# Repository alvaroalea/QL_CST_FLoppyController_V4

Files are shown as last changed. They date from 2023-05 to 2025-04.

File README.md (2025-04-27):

# QL_CST_FLoppyController

A clone of some version of the CST's Floppy Disk Interface for Sinclair QL

## History

CST was one of the main manufacturer of add-on for the Sinclair QL computer, this include backplanes, memory expansions and disc interfaces.

The Disk interface evolved over several version, with enhaced compatibilities in each version.

- Issue 1 - I can't get information about this Issue on internet.
- Issue 2 - This version use ReVision 1.13 (C) 1985 of the ROM, of 8Kb, Nicolaos Doukas draw the schematic an create a clone. Is possible to upgrade Issue 2 to ROM 1.16 if isolate the PIN 3 of IC3 (74LS03).
- Issue 3 - This version use Revision 1.16 (C) 198X of the ROM, of 8Kb, new clock circuit and 1 missing track on the PCB (and this is the reason you need to isolate pin 3 on Issue 2)
- Issue 4 - This version use Revision 1.18 (C) 1986 /1.19 (C) 1987 of the ROM, diferent circuit, increase the ROM size to 12Kb (use a 16Kb Eprom chip), now include RAM disk driver in rom, this version se a scrambled ROM, so when read with a external device, you can see the code.

Version 1.19 of ROM is missing in action, other version area available to download here: https://dilwyn.theqlforum.com/qlrom/index.html

Has been seen version of Issue 4 with, the top/botton cooper tracks interchanged, this help to reverse engineered the complete board.

Nowday I have draw and test the PCB of Issue 3 and 4, they are in separate folders, including, manuals and and ROM image.

## The Board

It use the standar stugart conector, so a plain cable can have up to 2 disk drives, that shall be correctly configured as DS0 and DS1.

It use a WD1770 disc controller, and is expected that will be compatible with WD1772 (not checked), WD1773 is not compatible.

Thanks to Derek_Stewart and techy of qlforum.co.uk for providing the pictures that allow me to capture the schema.

A interactive bill of materials for each board is available here:

* https://alvaroalea.github.io/QL_CST_FLoppyController/ibom_3.html
* https://alvaroalea.github.io/QL_CST_FLoppyController/ibom_4.html

### WARNING: Use good components!

During testing we found that bulk unknow 2N2222 transistor seen to work, but have hard compatibility problems with other boards.

Using a wellknow source transistor eliminate the incompatibility and work correctly with other passthrough boards. Be aware if you use a external or internal RAM expansion, a Qbide with passtrough or a backplane that allow several boarda.

## Recreated Boards

### Issue 4

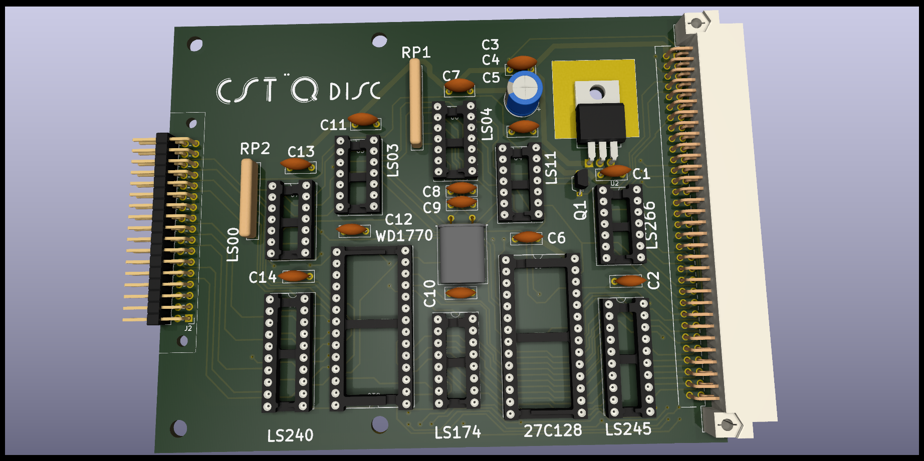
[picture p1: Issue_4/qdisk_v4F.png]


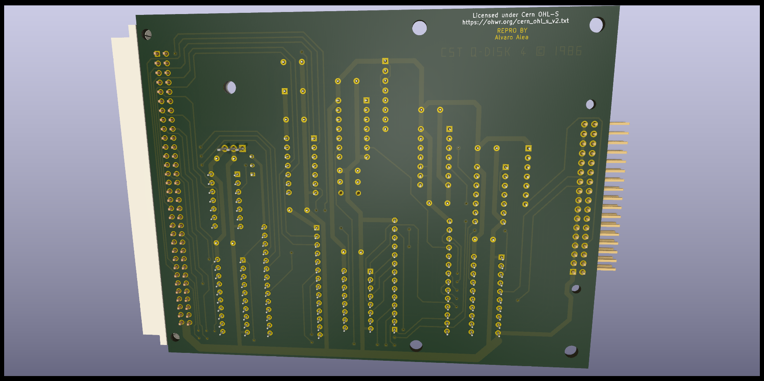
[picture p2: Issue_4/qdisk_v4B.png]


### Issue 3

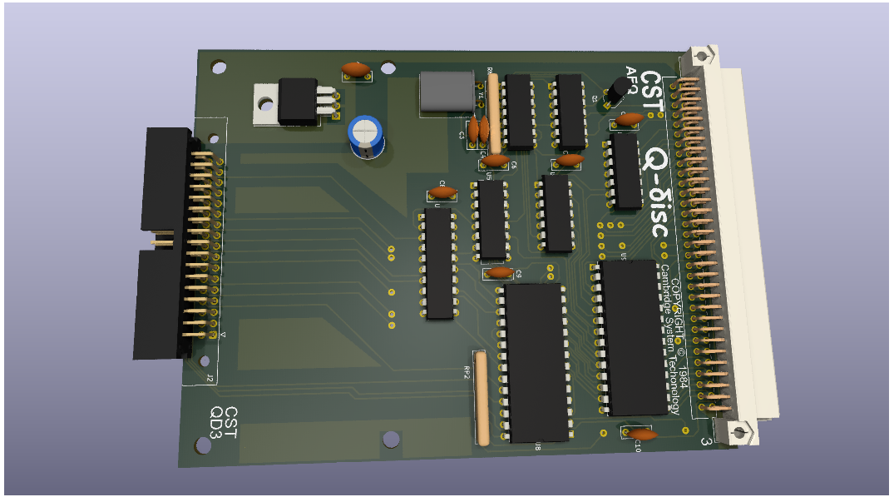
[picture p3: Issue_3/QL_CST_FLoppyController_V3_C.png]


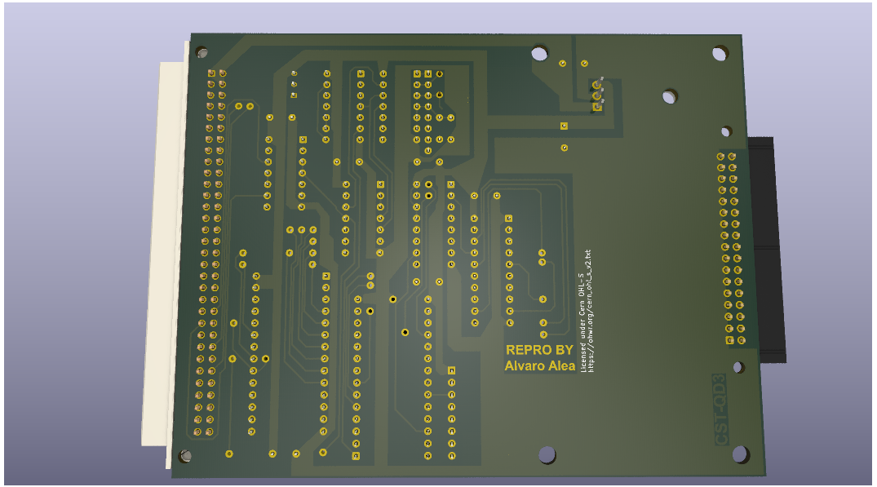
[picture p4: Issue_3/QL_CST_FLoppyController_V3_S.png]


## Original Boards

### Issue 2

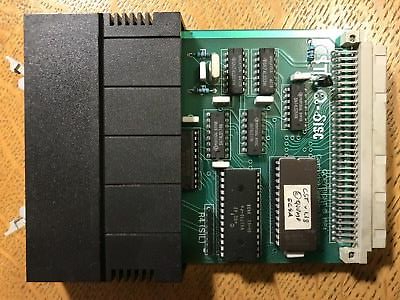
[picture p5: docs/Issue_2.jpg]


One of the few images available on internet, noted the transistor near the edge conector, 3 resistor on top of the PCB, two of this near the crystal, and the resistor array near WD1770 is called R4 (SIL)

### Issue 3

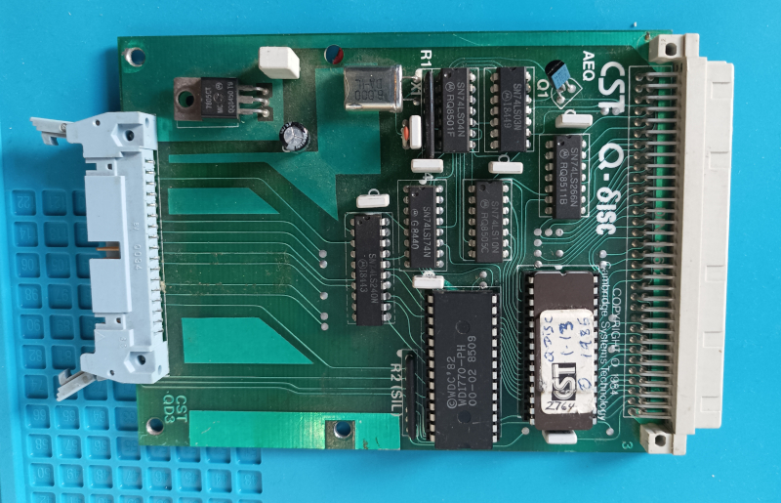
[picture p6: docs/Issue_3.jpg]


The transistor has been moved, the 3 resistor has been replaces by array R1, and the resistor array near WD1770 is called R2 (SIL)

### Issue 4

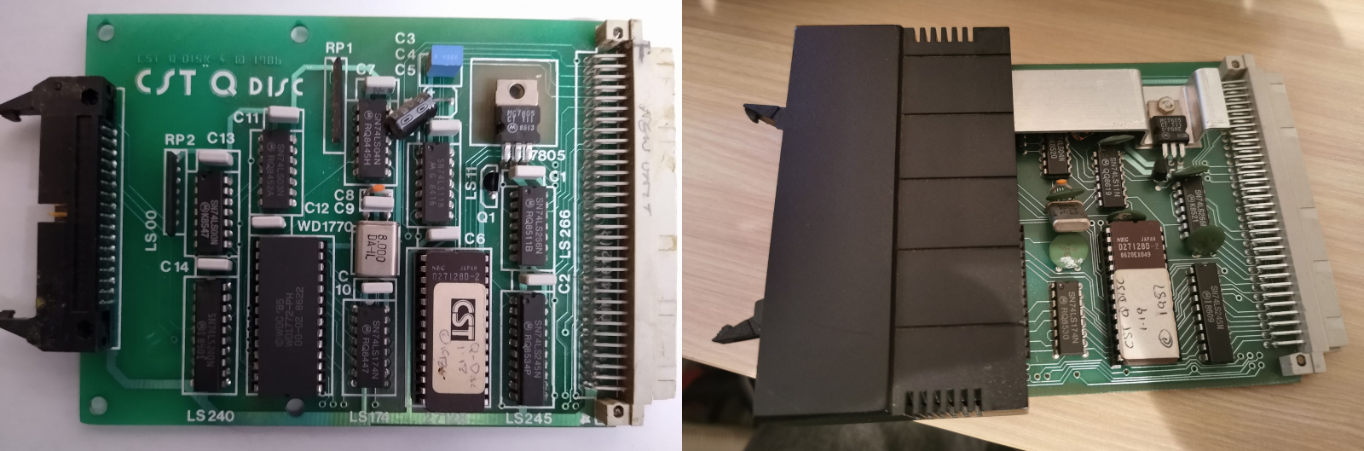
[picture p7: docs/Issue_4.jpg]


Complete new PCB, note The right one, with top/botton layer correct, but without silkscreen, and the left, with silkscreen but top/botton swapped (and exposed tracks under heat disipator).

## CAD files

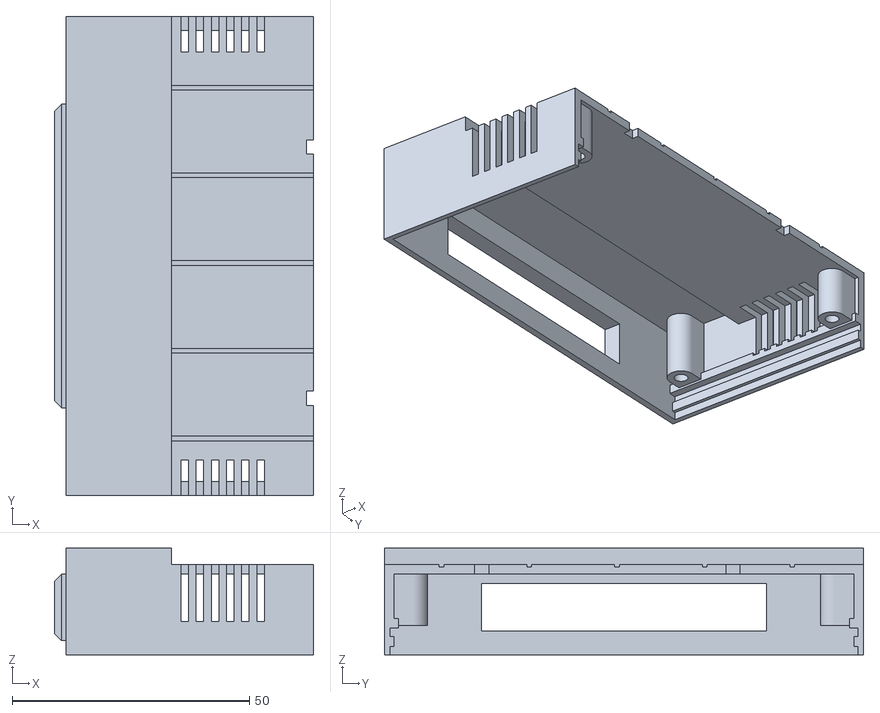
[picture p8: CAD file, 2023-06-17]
3D/case.stl
54.7 x 101.0 x 22.5

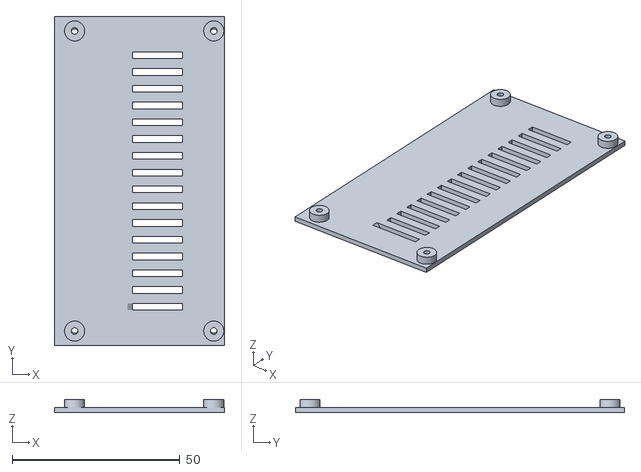
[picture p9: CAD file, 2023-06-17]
3D/lid.stl
50.7 x 98.2 x 3.95

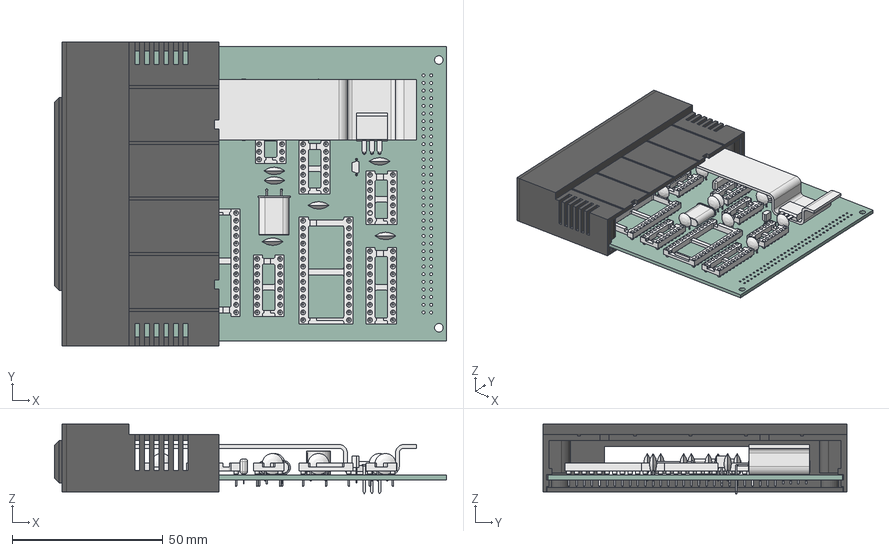
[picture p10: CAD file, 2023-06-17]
3D/carcasa_V2.FCStd
130.2 x 101.0 x 23.2 mm
tapa_inferior
qdisk_v4 PCB

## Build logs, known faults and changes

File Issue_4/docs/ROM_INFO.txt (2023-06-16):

MENSAJES / MESSAGES
===================
CST QDisc  Controller V 1.18  1986
files still open
read/write failed
rom checksum failure

COMANDOS / COMMANDS
===================
* EW
* EX
* EXEC_W
* EXEC
* SPL
* JOBS
* RJOB
* SPJOB
* GET
* BGET
* PUT
* BPUT
* RENAME
* TRUNCATE
* VIEW
* WCOPY
* STAT
* WSTAT
* WDIR
* WDEL
* WDEL_F
* PROG_USE
* DATA_USE
* SPL_USE
* RAM_USE
* FLP_USE
* FLP_SEC
* FLP_START
* FLP_TRACK
* CURSEN
* CURDIS
* RECHP
* CLCHP
* EXTRAS
* CHAR_USE
* CHAR_INC
* WMON
* WTV
* CLOCK
* FPOS
* FLEN
* FTYP
* FDAT
* FOPEN
* FOP_IN
* FOP_NEW
* FOP_OVER
* FOP_DIR
* HEX$
* BIN$
* FDEC$
* IDEC$
* CDEC$
* HEX
* BIN
* FREE_MEM
* ALCHP
* PARTYP
* PARUSE

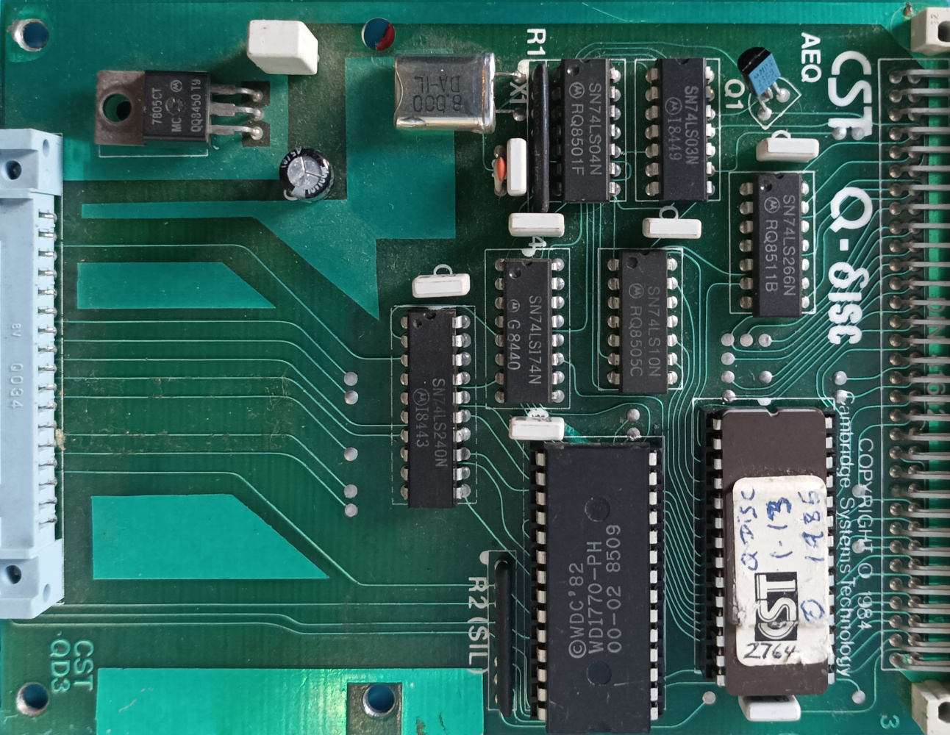
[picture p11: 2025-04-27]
Issue_3/docs/qdisc3_f.jpg

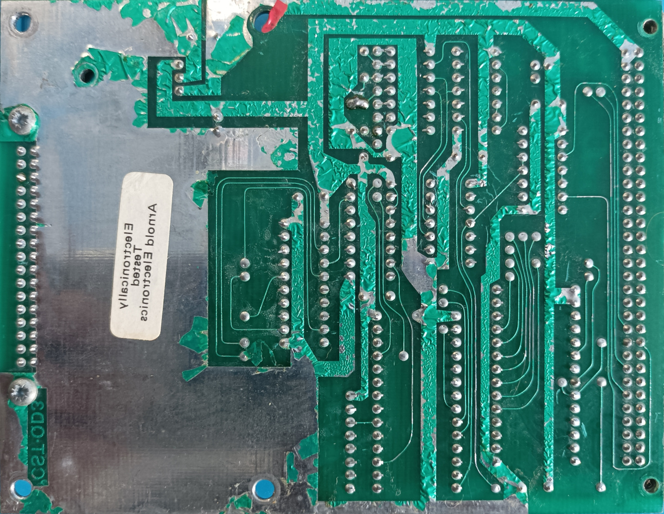
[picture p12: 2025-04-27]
Issue_3/docs/qdisc3_b.jpg

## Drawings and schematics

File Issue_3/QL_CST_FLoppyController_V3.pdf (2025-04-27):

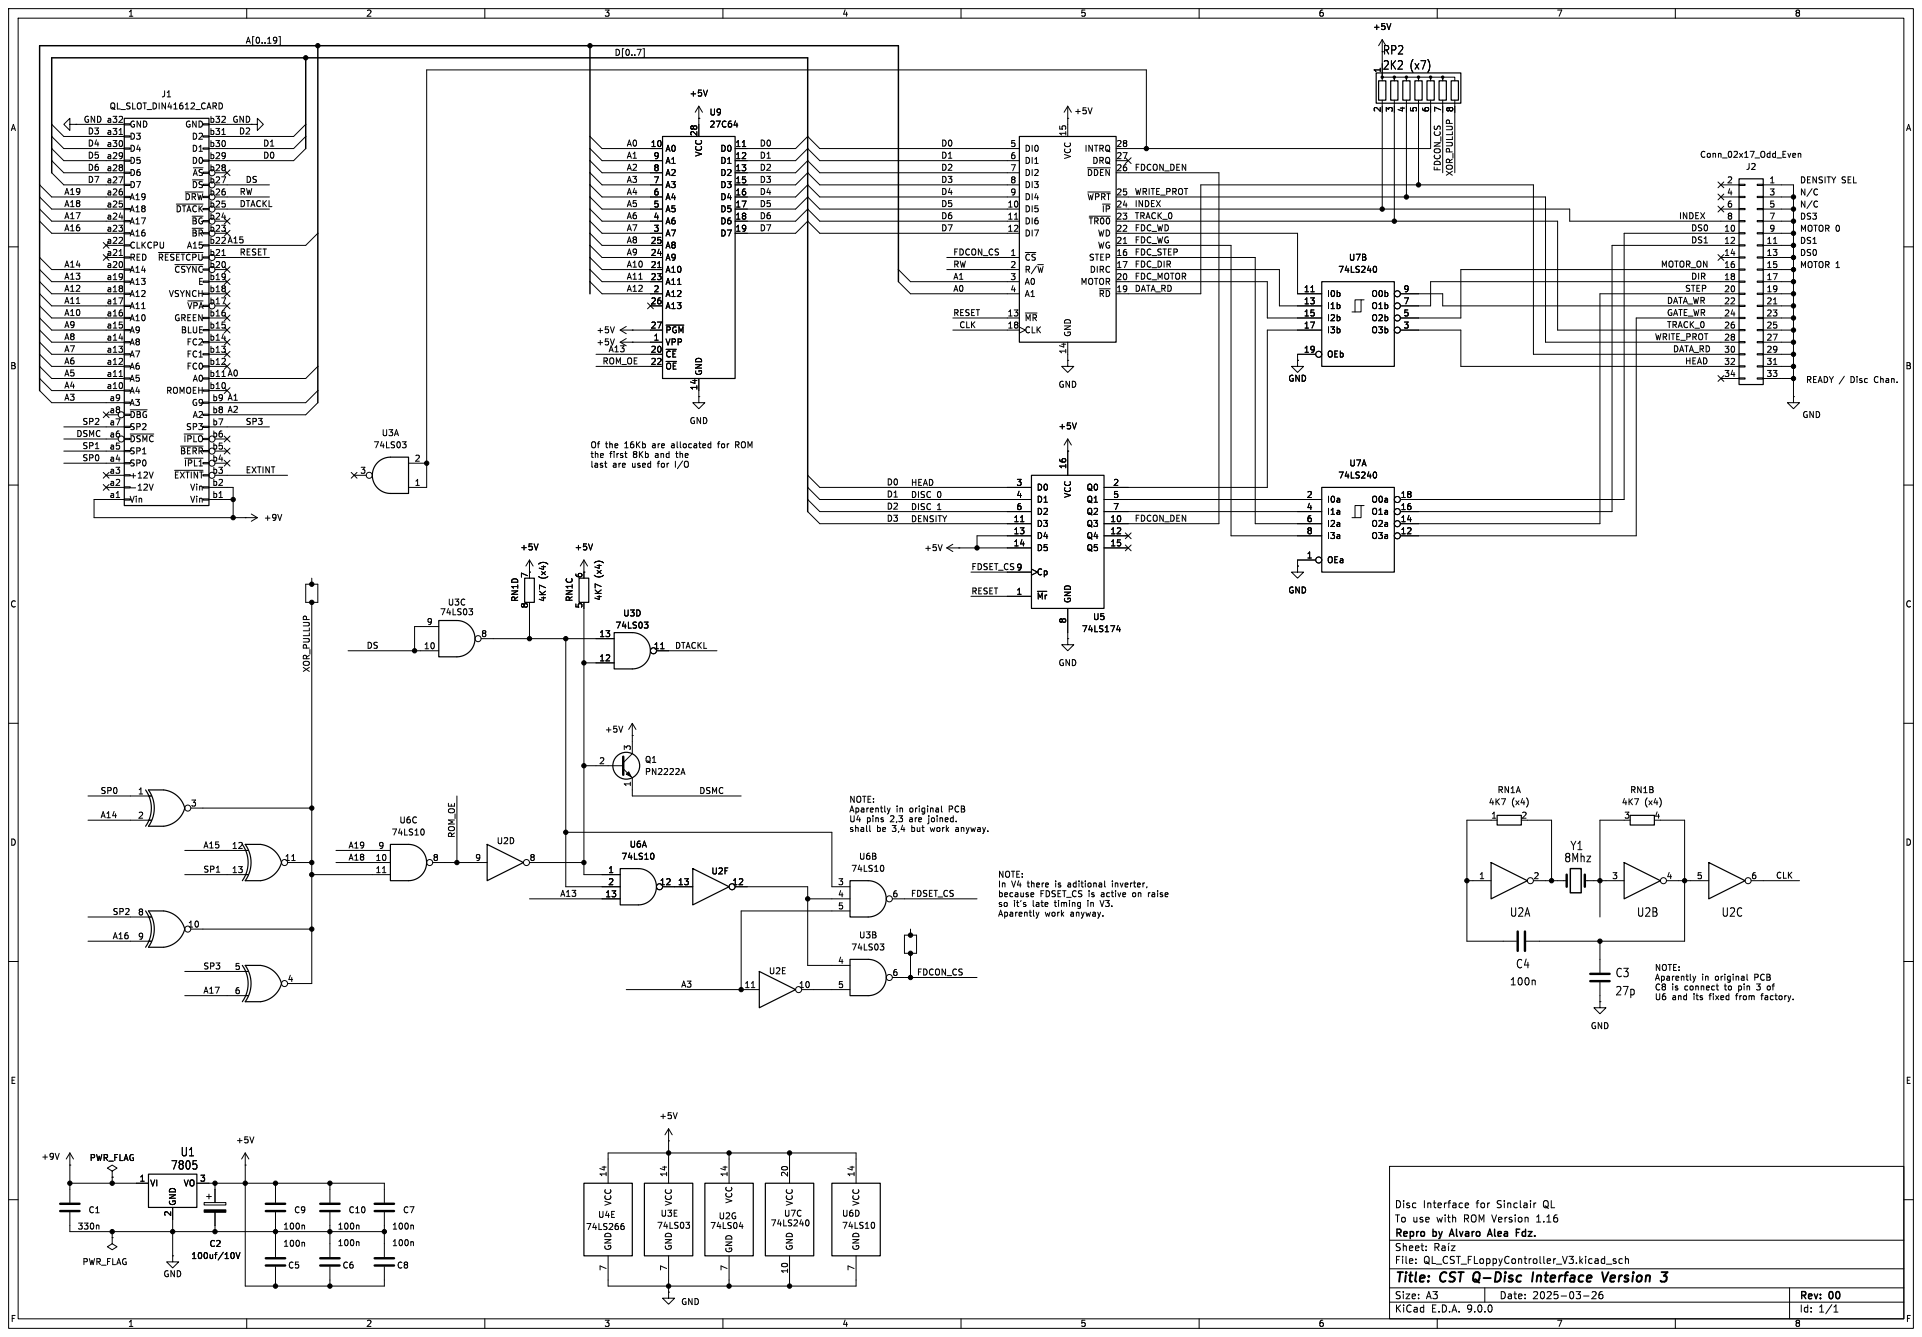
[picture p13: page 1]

GND a32 D3 a31 D4 a30 D5 a29 D6 a28 D7 a27 A19 a26 A18 a25 A17 a24 A16 a23 CLKCPU a22 RED a21 A14 a20 A13 a19 A12 a18 A11 a17 A10 a16 A9 a15 A8 a14 A7 a13 A6 a12 A5 a11 A4 a10 A3 a9 ~{DBG} a8 SP2 a7 ~{DSMC} a6 SP1 a5 SP0 a4 +12V a3

b19 VSYNCH b18 ~{VPA}b17 GREEN b16 BLUE b15 FC2 b14 FC1 b13 FC0 b12 A0 b11 ROMOEH b10 G9 b9 A2 b8 SP3 b7 ~{IPLO}b6 ~{BERR}b5 ~{IPL1}b4 ~{EXTINT}b3 Vin b2 Vin b1

the first 8Kb and the
last are used for I/O

so it's late timing in V3. Aparently work anyway.

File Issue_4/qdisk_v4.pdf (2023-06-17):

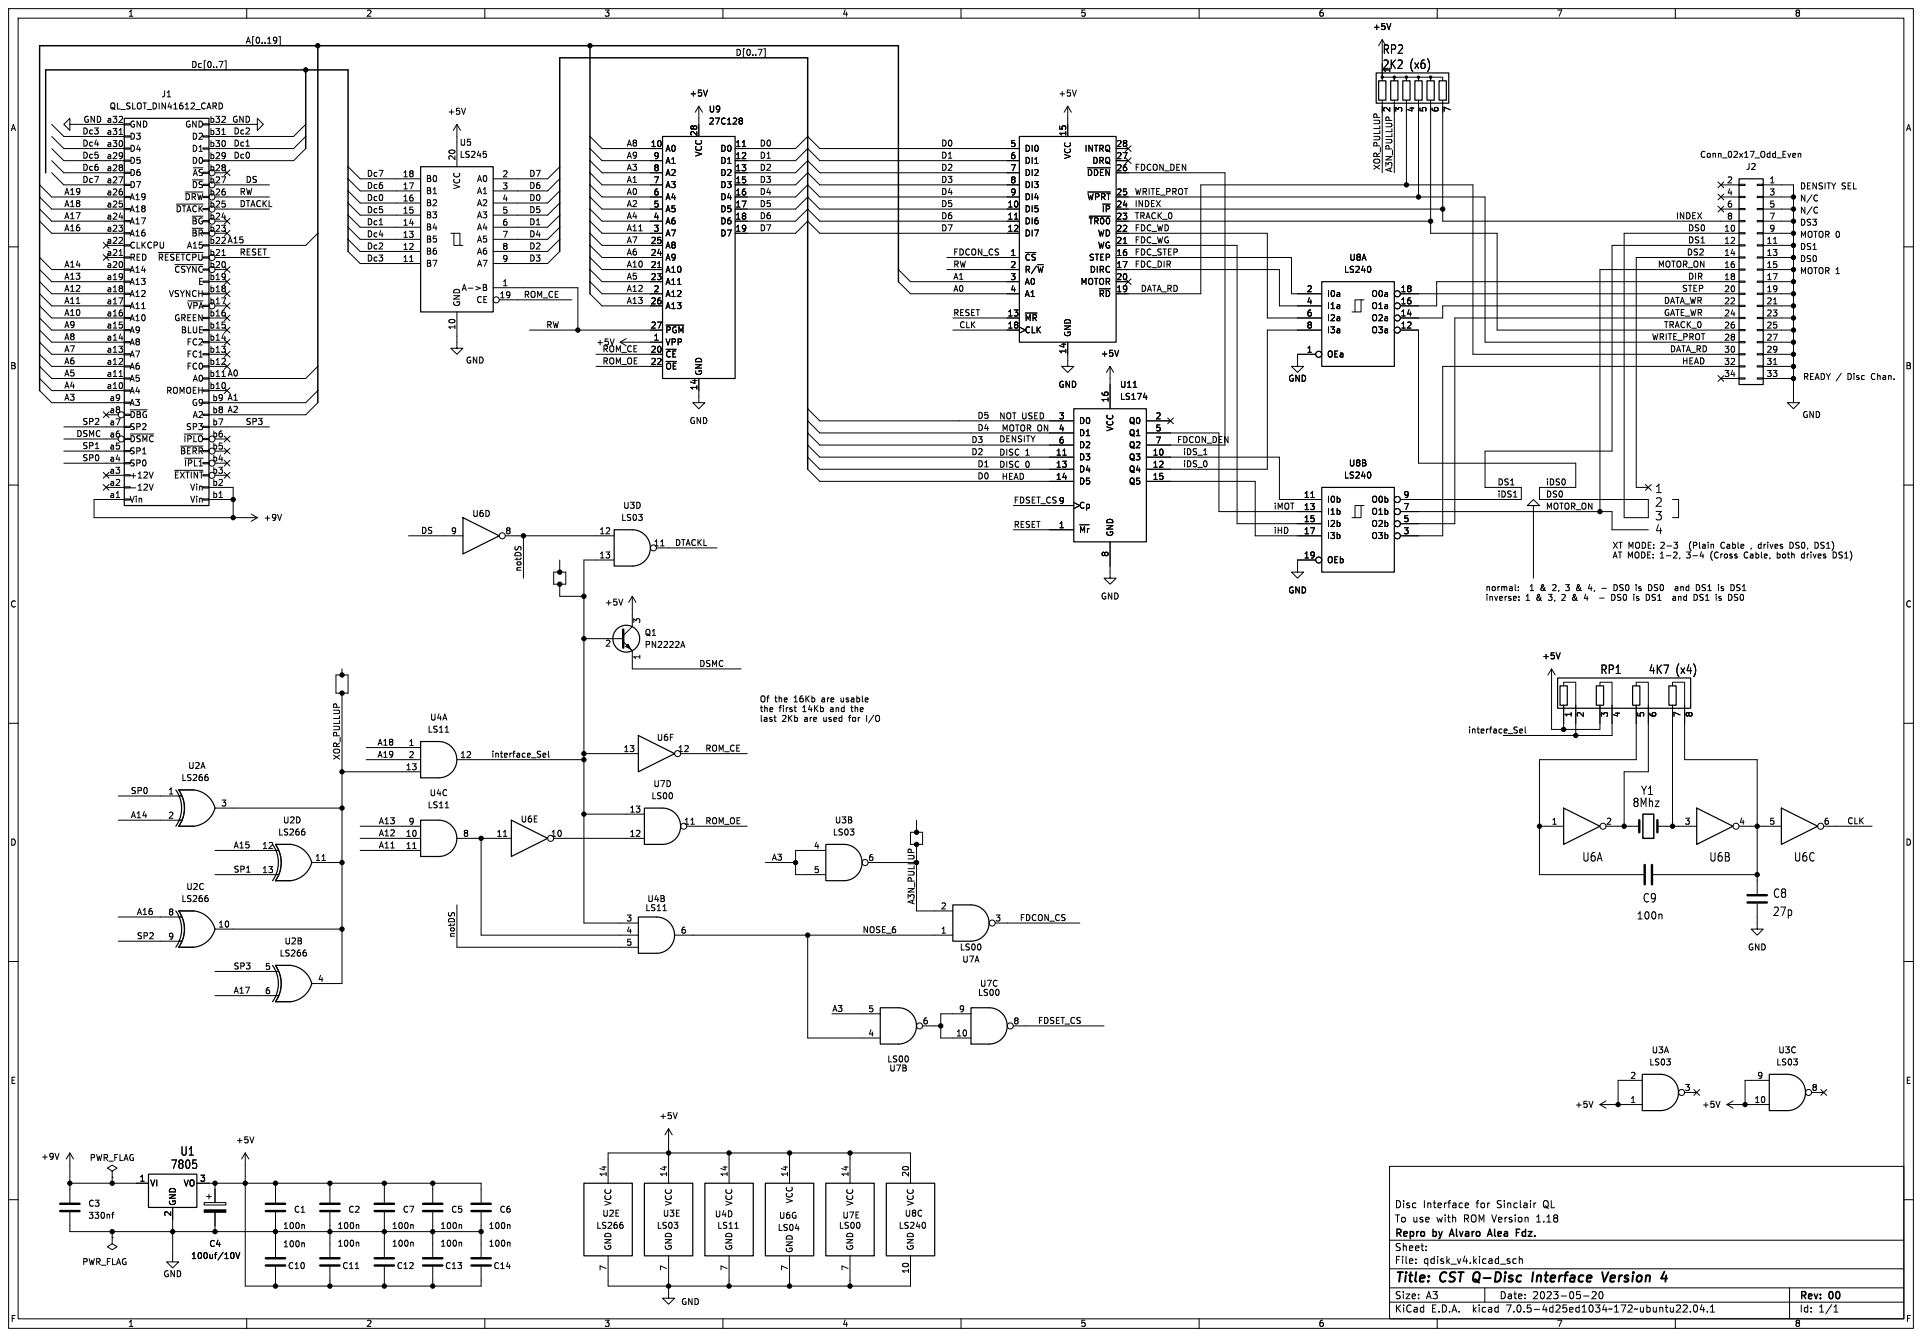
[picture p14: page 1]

b19 Vin b2 ~{CSYNC}b20 ~{RESETCPU}b21 A15 b22 ~{BR}b23 ~{BG}b24 ~{DTACK}b25 ~{DRW}b26 ~{DS}b27 ~{AS}b28 D0 b29 ~{EXTINT}b3 D1 b30 D2 b31 GND b32 ~{IPL1}b4 ~{BERR}b5 ~{IPLO}b6 SP3 b7 A2 b8 G9 b9

DISC 1 NOT USED
inverse: 1 & 3, 2 & 4 - DS0 is DS1 and DS1 is DS0 MOTOR ON

Of the 16Kb are usable
the first 14Kb and the
last 2Kb are used for I/O

Id: 1/1 Title: CST Q-Disc Interface Version 4

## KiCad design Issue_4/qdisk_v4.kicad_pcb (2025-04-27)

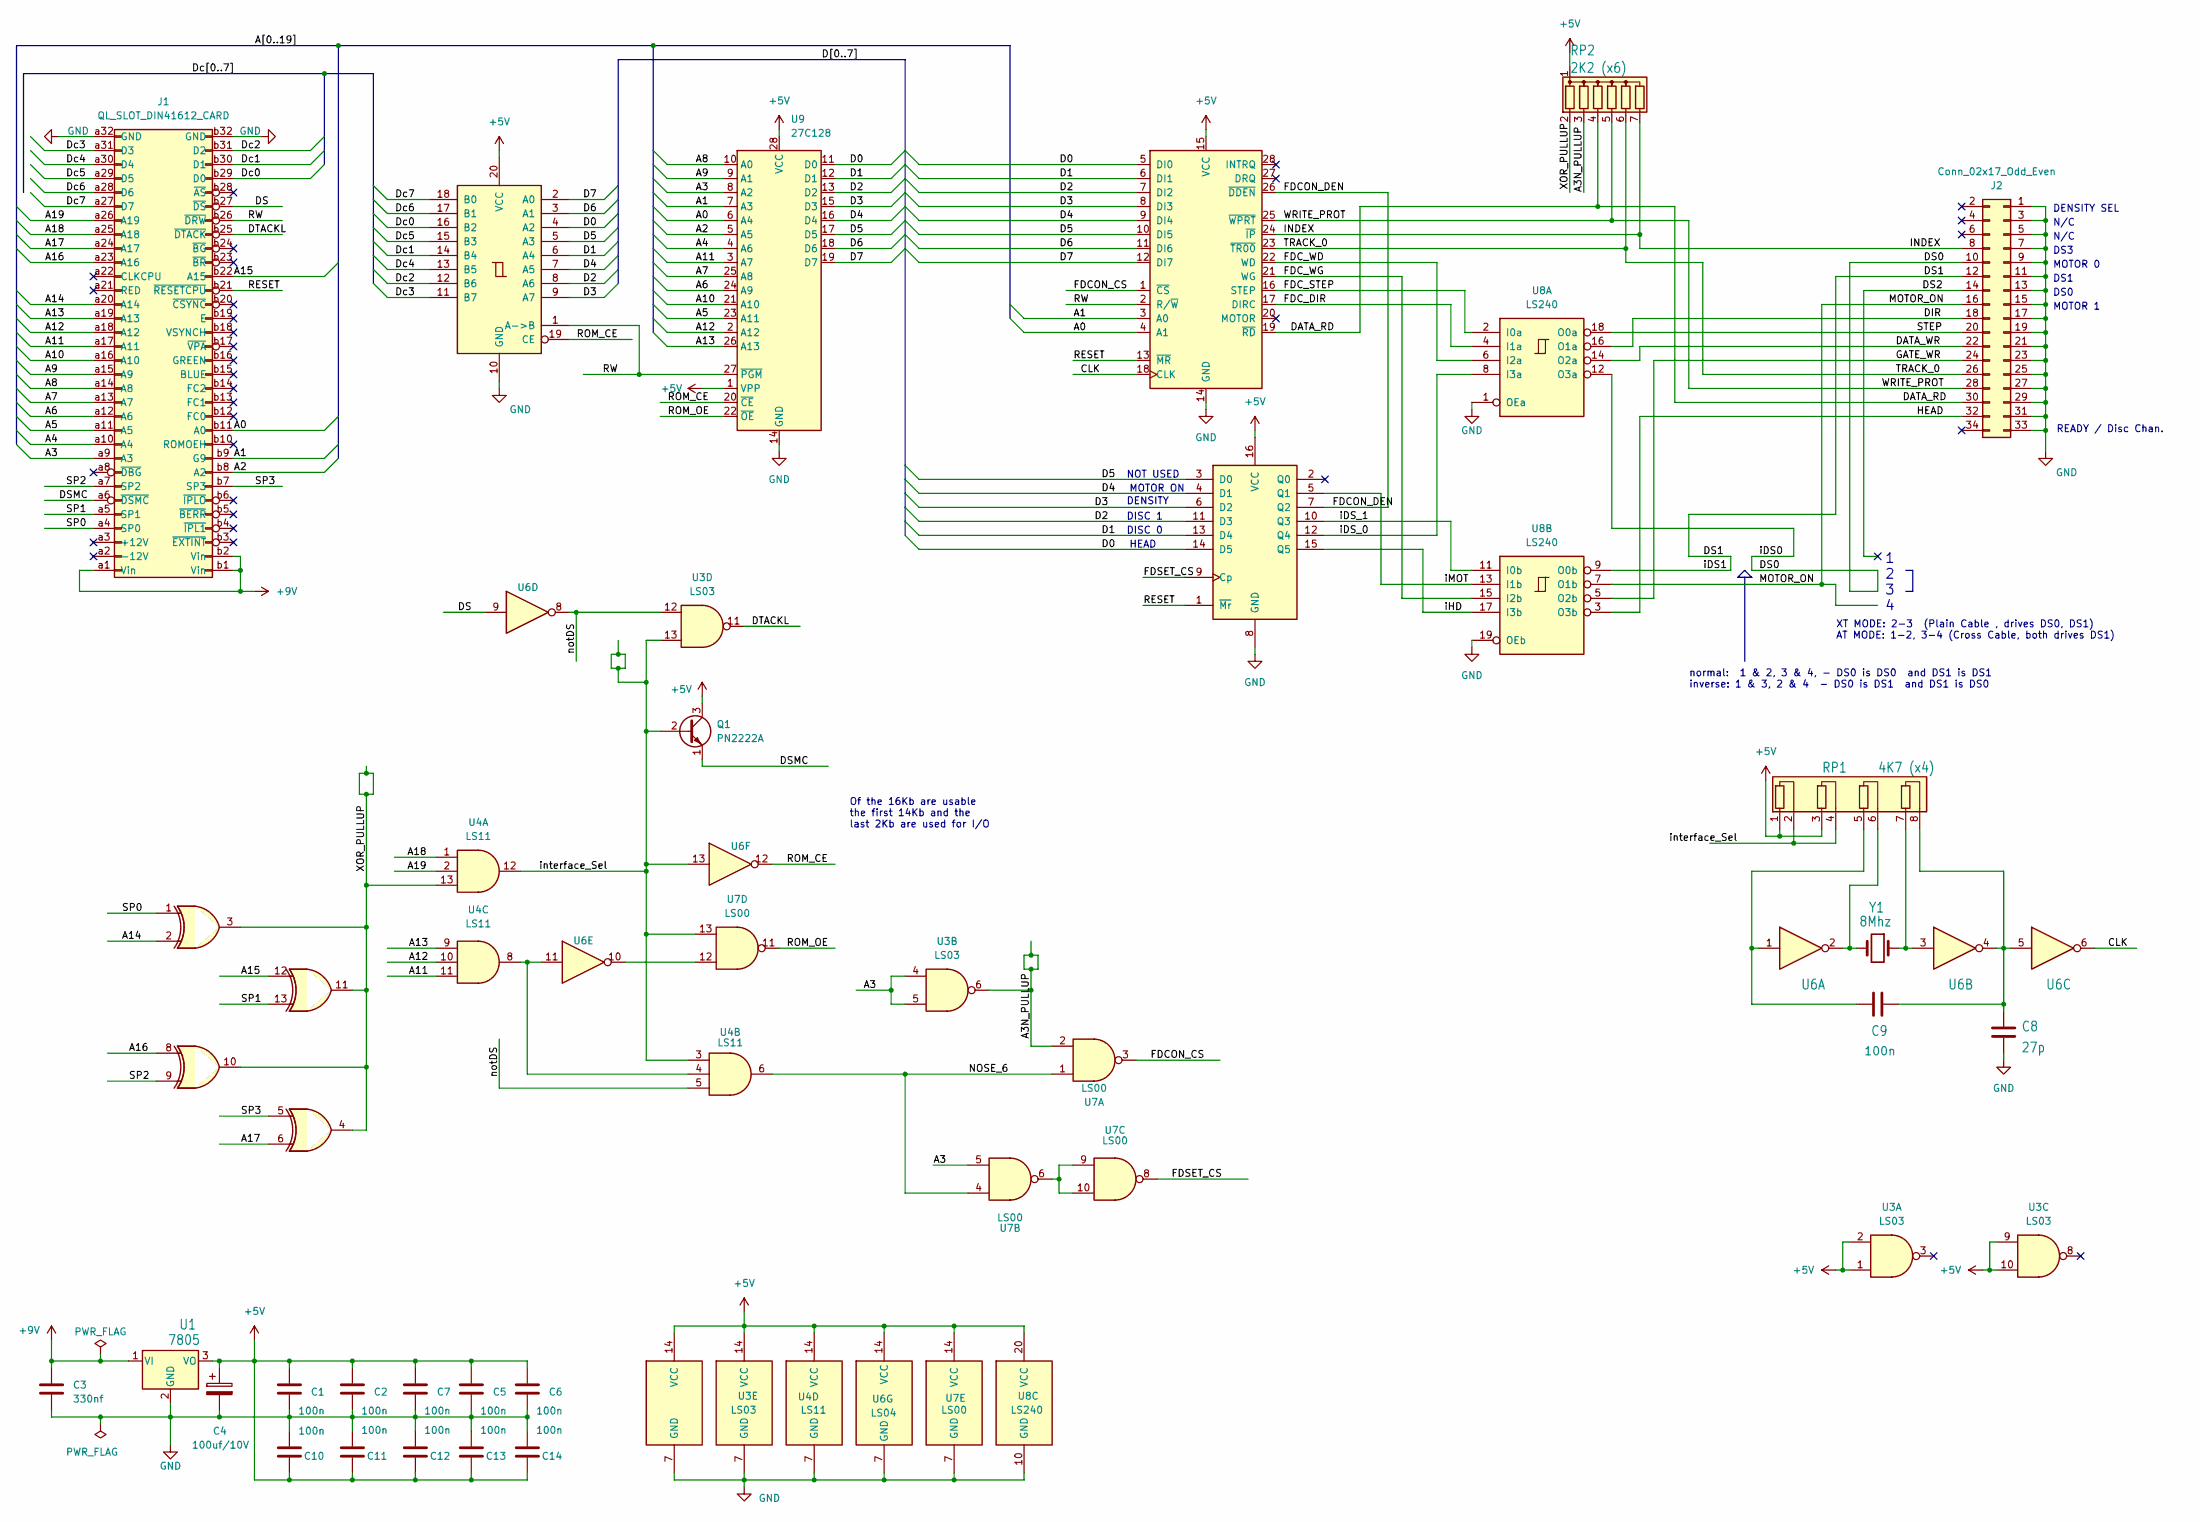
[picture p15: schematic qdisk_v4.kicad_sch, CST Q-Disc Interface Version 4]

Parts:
C1, C2, C5, C6, C7, C9, C10, C11, C12, C13, C14: 100n; C_Disc_D7.0mm_W2.5mm_P5.00mm
C3: 330nf; C_Disc_D7.0mm_W2.5mm_P5.00mm
C4: 100uf/10V; CP_Radial_D8.0mm_P5.00mm
C8: 27p; C_Disc_D7.0mm_W2.5mm_P5.00mm
J1: QL_SLOT_DIN41612_CARD; DIN41612_B_2x32_Female_Horizontal_THT
J2: Conn_02x17_Odd_Even; IDC-Header_2x17_P2.54mm_Latch_Horizontal
Q1: PN2222A; TO-92S_Wide
RP1: 4K7 (x4); R_Array_SIP8
RP2: 2K2 (x6); R_Array_SIP7
U1: 7805; TO-220-3_Horizontal_TabDown
U2: 74LS266; DIP-14_W7.62mm
U3: LS03; DIP-14_W7.62mm_Socket
U4: LS11; DIP-14_W7.62mm_Socket
U5: 74LS245; DIP-20_W7.62mm_Socket
U6: LS04; DIP-14_W7.62mm_Socket
U7: LS00; DIP-14_W7.62mm_Socket
U8: LS240; DIP-20_W7.62mm_Socket
U9: 27C128; DIP-28_W15.24mm_Socket
U10: FDC_WD1772; DIP-28_W15.24mm
U11: 74LS174; DIP-16_W7.62mm_Socket
Y1: 8Mhz; Crystal_HC18-U_Horizontal

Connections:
+5V: C1.1, C2.1, C4.1, C5.1, C6.1, C7.1, C10.1, C11.1, C12.1, C13.1, C14.1, Q1.3 (C), RP1.1 (R1.1), RP1.3 (R2.1), RP2.1 (common), U1.3 (VO), U2.14 (VCC), U3.1, U3.2, U3.9, U3.10, U3.14 (VCC), U4.14 (VCC), U5.20 (VCC), U6.14 (VCC), U7.14 (VCC), U8.20 (VCC), U9.1 (VPP), U9.28 (VCC), U10.15 (VCC), U11.16 (VCC)
+9V: C3.1, J1.a1 (Vin), J1.b1 (Vin), J1.b2 (Vin), U1.1 (VI)
/A0: J1.b11 (A0), U9.6 (A4), U10.4 (A1)
/A1: J1.b9 (G9), U9.7 (A3), U10.3 (A0)
/A2: J1.b8 (A2), U9.5 (A5)
/A3: J1.a9 (A3), U3.4, U3.5, U7.5, U9.8 (A2)
/A3N_PULLUP: RP2.3 (R2), U3.6, U7.2
/A4: J1.a10 (A4), U9.4 (A6)
/A5: J1.a11 (A5), U9.23 (A11)
/A6: J1.a12 (A6), U9.24 (A9)
/A7: J1.a13 (A7), U9.25 (A8)
/A8: J1.a14 (A8), U9.10 (A0)
/A9: J1.a15 (A9), U9.9 (A1)
/A10: J1.a16 (A10), U9.21 (A10)
/A11: J1.a17 (A11), U4.11, U9.3 (A7)
/A12: J1.a18 (A12), U4.10, U9.2 (A12)
/A13: J1.a19 (A13), U4.9, U9.26 (A13)
/A14: J1.a20 (A14), U2.2
/A15: J1.b22 (A15), U2.12
/A16: J1.a23 (A16), U2.8
/A17: J1.a24 (A17), U2.6
/A18: J1.a25 (A18), U4.1
/A19: J1.a26 (A19), U4.2
/CLK: U6.6, U10.18 (CLK)
/D0: U5.4 (A2), U9.11 (D0), U10.5 (DI0), U11.14 (D5)
/D1: U5.6 (A4), U9.12 (D1), U10.6 (DI1), U11.13 (D4)
/D2: U5.8 (A6), U9.13 (D2), U10.7 (DI2), U11.11 (D3)
/D3: U5.9 (A7), U9.15 (D3), U10.8 (DI3), U11.6 (D2)
/D4: U5.7 (A5), U9.16 (D4), U10.9 (DI4), U11.4 (D1)
/D5: U5.5 (A3), U9.17 (D5), U10.10 (DI5), U11.3 (D0)
/D6: U5.3 (A1), U9.18 (D6), U10.11 (DI6)
/D7: U5.2 (A0), U9.19 (D7), U10.12 (DI7)
/DATA_RD: J2.30, RP2.4 (R3), U10.19 (~RD)
/DATA_WR: J2.22, U8.14 (O2a)
/DIR: J2.18, U8.16 (O1a)
/DS: J1.b27 (~DS), U6.9
/DS0: J2.10, U8.12 (O3a)
/DS1: J2.12, U8.9 (O0b)
/DS2: J2.14
/DSMC: J1.a6 (~DSMC), Q1.1 (E)
/DTACKL: J1.b25 (~DTACK), U3.11
/Dc0: J1.b29 (D0), U5.16 (B2)
/Dc1: J1.b30 (D1), U5.14 (B4)
/Dc2: J1.b31 (D2), U5.12 (B6)
/Dc3: J1.a31 (D3), U5.11 (B7)
/Dc4: J1.a30 (D4), U5.13 (B5)
/Dc5: J1.a29 (D5), U5.15 (B3)
/Dc6: J1.a28 (D6), U5.17 (B1)
/Dc7: J1.a27 (D7), U5.18 (B0)
/FDCON_CS: U7.3, U10.1 (~CS)
/FDCON_DEN: U10.26 (~DDEN), U11.7 (Q2)
/FDC_DIR: U8.4 (I1a), U10.17 (DIRC)
/FDC_STEP: U8.2 (I0a), U10.16 (STEP)
/FDC_WD: U8.6 (I2a), U10.22 (WD)
/FDC_WG: U8.15 (I2b), U10.21 (WG)
/FDSET_CS: U7.8, U11.9 (Cp)
/GATE_WR: J2.24, U8.5 (O2b)
/HEAD: J2.32, U8.3 (O3b)
/INDEX: J2.8, RP2.7 (R6), U10.24 (~IP)
/MOTOR_ON: J2.16, U8.7 (O1b)
/NOSE_6: U4.6, U7.1, U7.4
/RESET: J1.b21 (~RESETCPU), U10.13 (~MR), U11.1 (~Mr)
/ROM_CE: U5.19 (CE), U6.12, U9.20 (~CE)
/ROM_OE: U7.11, U9.22 (~OE)
/RW: J1.b26 (~DRW), U5.1 (A->B), U9.27 (~PGM), U10.2 (R/~W)
/SP0: J1.a4 (SP0), U2.1
/SP1: J1.a5 (SP1), U2.13
/SP2: J1.a7 (SP2), U2.9
/SP3: J1.b7 (SP3), U2.5
/STEP: J2.20, U8.18 (O0a)
/TRACK_0: J2.26, RP2.6 (R5), U10.23 (~TR00)
/WRITE_PROT: J2.28, RP2.5 (R4), U10.25 (~WPRT)
/XOR_PULLUP: RP2.2 (R1), U2.3, U2.4, U2.10, U2.11, U4.13
/iDS_0: U8.8 (I3a), U11.12 (Q4)
/iDS_1: U8.11 (I0b), U11.10 (Q3)
/iHD: U8.17 (I3b), U11.15 (Q5)
/iMOT: U8.13 (I1b), U11.5 (Q1)
/interface_Sel: Q1.2 (B), RP1.2 (R1.2), RP1.4 (R2.2), U3.13, U4.3, U4.12, U6.13, U7.13
/notDS: U3.12, U4.5, U6.8
GND: C1.2, C2.2, C3.2, C4.2, C5.2, C6.2, C7.2, C8.2, C10.2, C11.2, C12.2, C13.2, C14.2, J1.a32 (GND), J1.b32 (GND), J2.1, J2.3, J2.5, J2.7, J2.9, J2.11, J2.13, J2.15, J2.17, J2.19, J2.21, J2.23, J2.25, J2.27, J2.29, J2.31, J2.33, U1.2 (GND), U2.7 (GND), U3.7 (GND), U4.7 (GND), U5.10 (GND), U6.7 (GND), U7.7 (GND), U8.1 (OEa), U8.10 (GND), U8.19 (OEb), U9.14 (GND), U10.14 (GND), U11.8 (GND)
unnamed: C9.2, RP1.5 (R3.1), U6.1
unnamed: RP1.6 (R3.2), U6.2, Y1.2
unnamed: RP1.7 (R4.1), U6.3, Y1.1
unnamed: C8.1, C9.1, RP1.8 (R4.2), U6.4, U6.5
unnamed: U4.4, U4.8, U6.11
unnamed: U6.10, U7.12
unnamed: U7.6, U7.9, U7.10

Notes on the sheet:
XT MODE: 2-3 (Plain Cable , drives DS0, DS1) AT MODE: 1-2, 3-4 (Cross Cable, both drives DS1)
NOT USED
MOTOR ON
MOTOR 0
HEAD
normal: 1 & 2, 3 & 4, - DS0 is DS0 and DS1 is DS1 inverse: 1 & 3, 2 & 4 - DS0 is DS1 and DS1 is DS0
DS0
DS1
READY / Disc Chan.
DENSITY
MOTOR 1
DS3
Of the 16Kb are usable the first 14Kb and the last 2Kb are used for I/O
N/C
1 2 3 4
DISC 1
DENSITY SEL
DISC 0

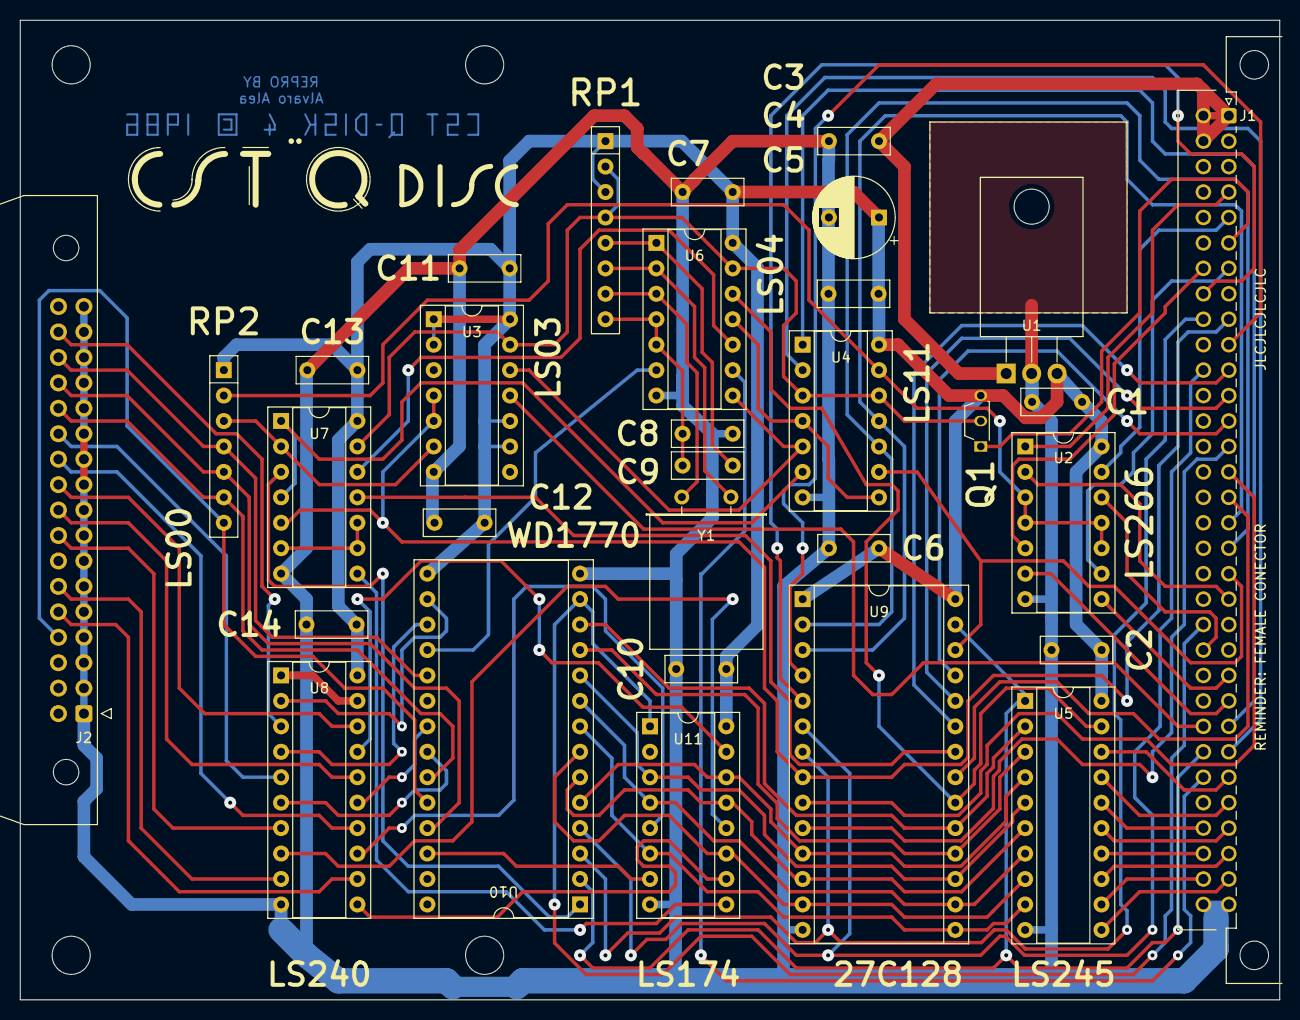
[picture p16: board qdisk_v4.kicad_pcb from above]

Board: 2 copper layers, 125.7 x 97.8 mm, 31 parts (0 on the bottom side), 86 nets.

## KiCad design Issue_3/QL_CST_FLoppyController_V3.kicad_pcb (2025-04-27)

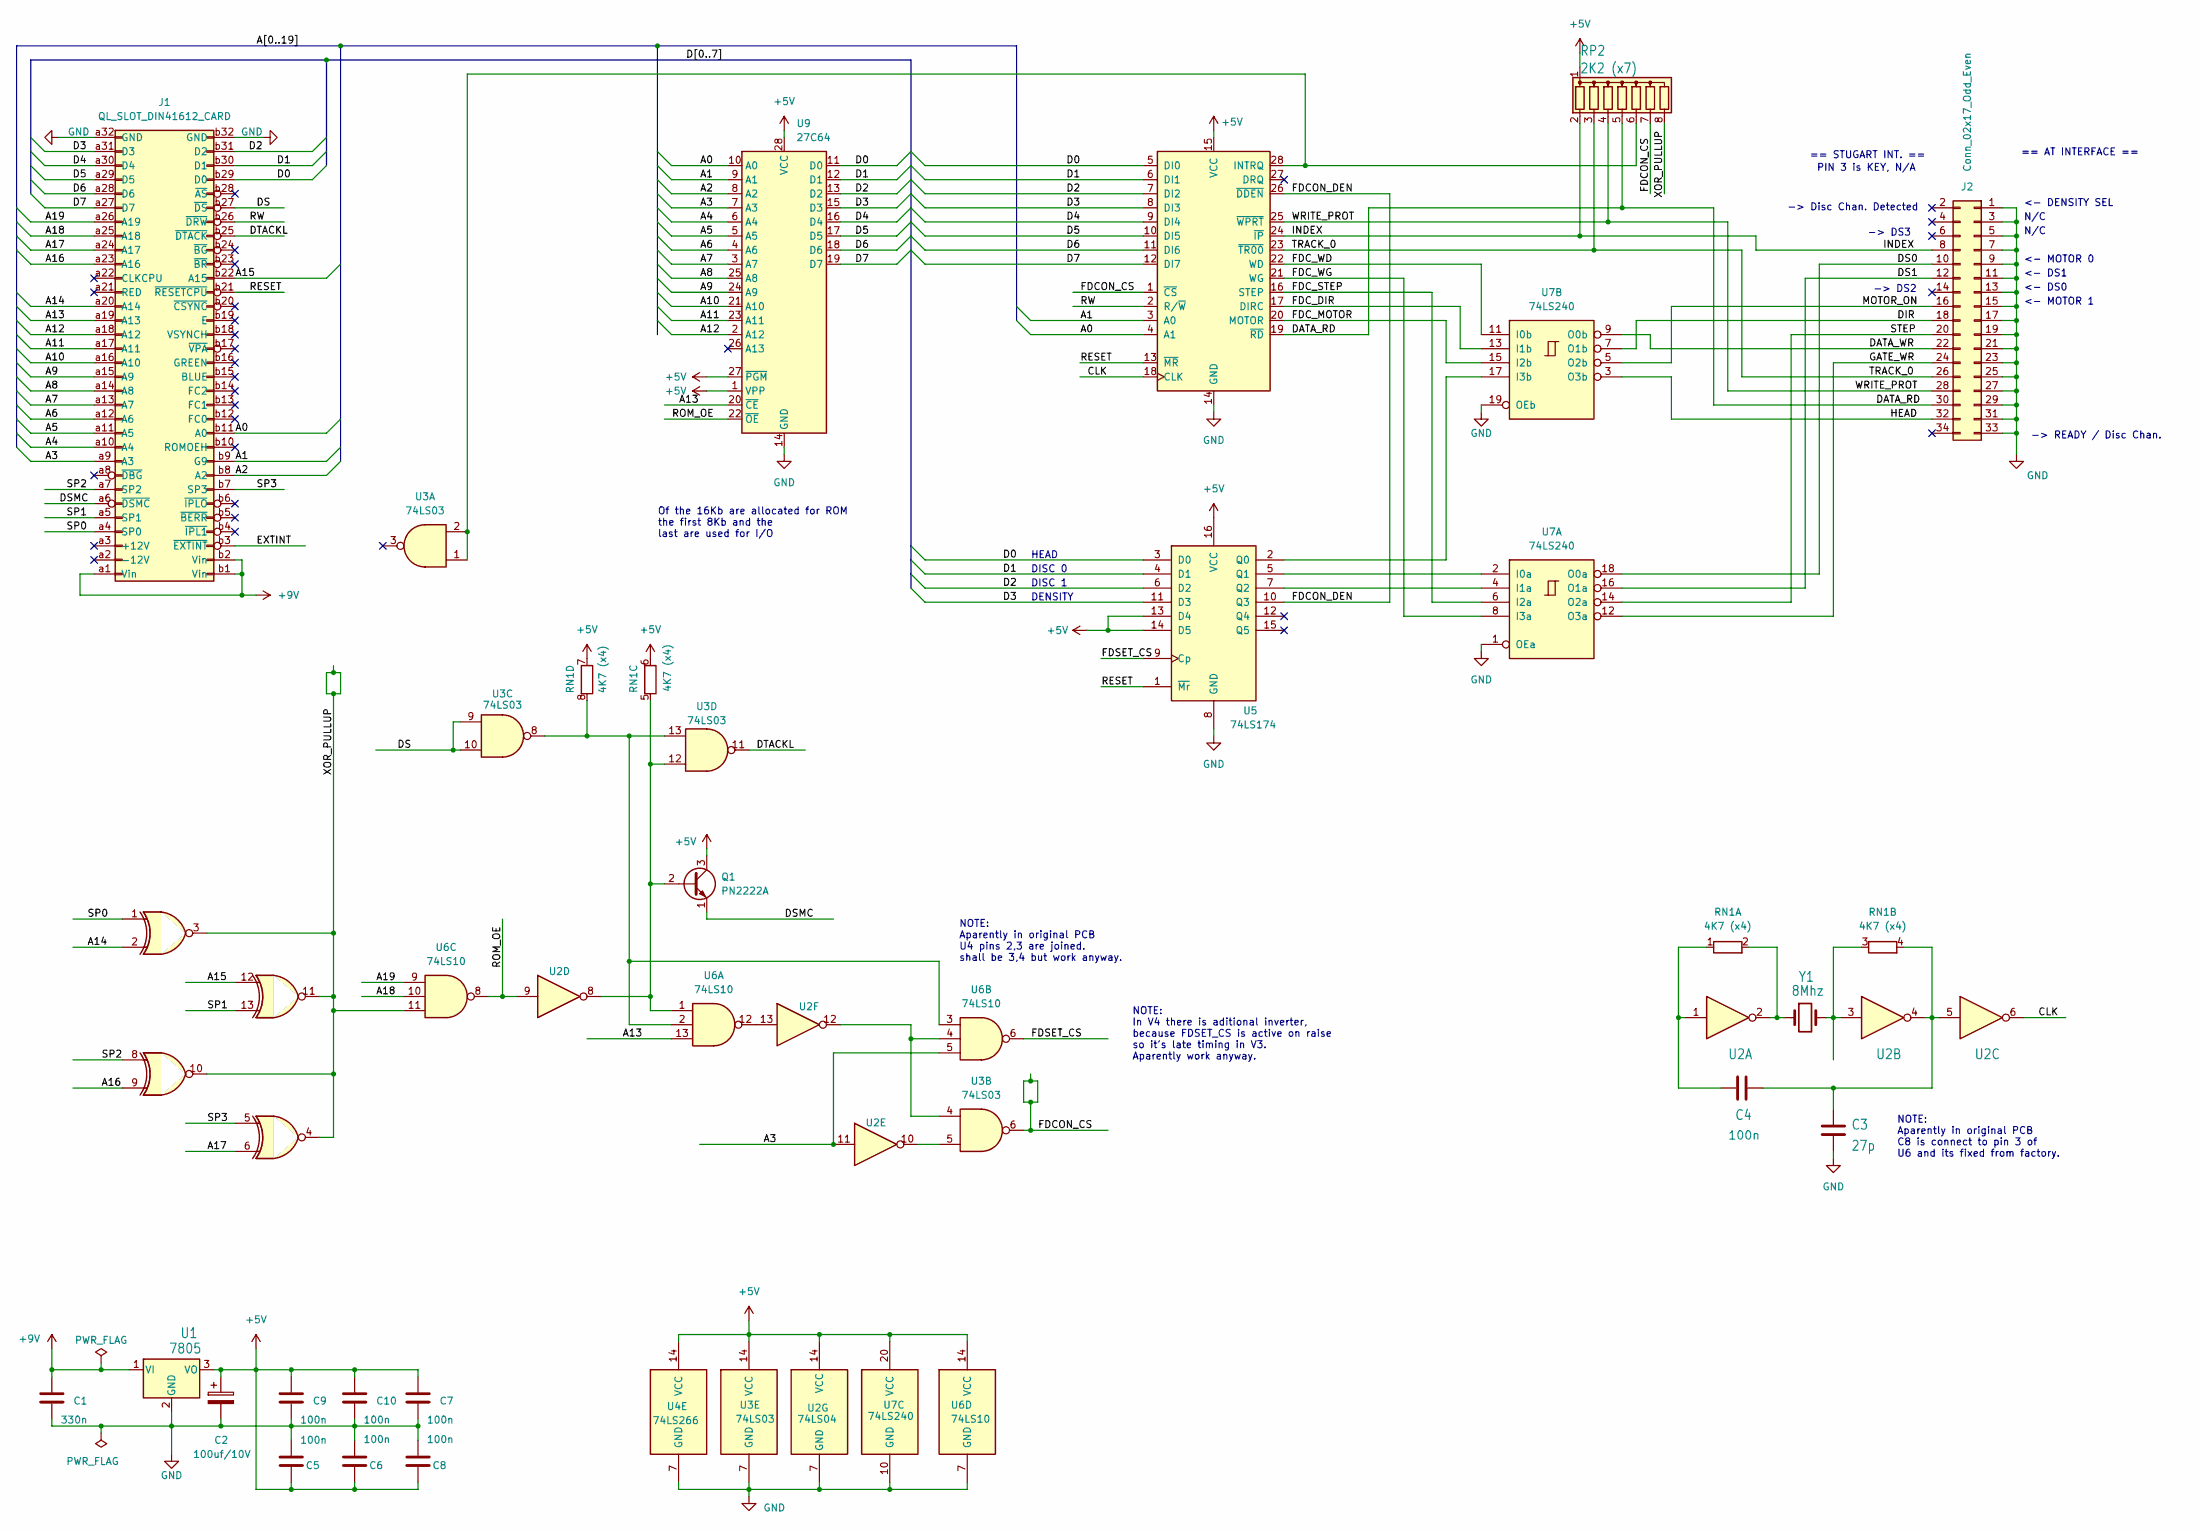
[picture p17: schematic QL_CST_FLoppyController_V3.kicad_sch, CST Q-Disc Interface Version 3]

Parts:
C1: 330n; C_Disc_D7.0mm_W2.5mm_P5.00mm
C2: 100uf/10V; CP_Radial_D8.0mm_P5.00mm
C3: 27p; C_Disc_D7.0mm_W2.5mm_P5.00mm
C4, C5, C6, C7, C8, C9, C10: 100n; C_Disc_D7.0mm_W2.5mm_P5.00mm
J1: QL_SLOT_DIN41612_CARD; DIN41612_B_2x32_Female_Horizontal_THT
J2: Conn_02x17_Odd_Even; IDC-Header_2x17_P2.54mm_Latch_Horizontal
Q1: PN2222A; TO-92_Wide
RN1: 4K7 (x4); R_Array_SIP8
RP2: 2K2 (x7); R_Array_SIP8
U1: 7805; TO-220-3_Horizontal_TabDown
U2: 74LS04; DIP-14_W7.62mm_Socket
U3: 74LS03; DIP-14_W7.62mm_Socket
U4: 74LS266; DIP-14_W7.62mm_Socket
U5: 74LS174; DIP-16_W7.62mm_Socket
U6: 74LS10; DIP-14_W7.62mm_Socket
U7: 74LS240; DIP-20_W7.62mm_Socket
U8: WD1772; DIP-28_W15.24mm_Socket
U9: 27C64; DIP-28_W15.24mm_Socket
Y1: 8Mhz; Crystal_HC18-U_Horizontal

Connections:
+5V: C2.1, C5.1, C6.1, C7.1, C8.1, C9.1, C10.1, Q1.3 (C), RN1.6 (R3.2), RN1.7 (R4.1), RP2.1 (common), U1.3 (VO), U2.14 (VCC), U3.14 (VCC), U4.14 (VCC), U5.13 (D4), U5.14 (D5), U5.16 (VCC), U6.14 (VCC), U7.20 (VCC), U8.15 (VCC), U9.1 (VPP), U9.27 (~PGM), U9.28 (VCC)
+9V: C1.1, J1.a1 (Vin), J1.b1 (Vin), J1.b2 (Vin), U1.1 (VI)
/A0: J1.b11 (A0), U8.4 (A1), U9.10 (A0)
/A1: J1.b9 (G9), U8.3 (A0), U9.9 (A1)
/A2: J1.b8 (A2), U9.8 (A2)
/A3: J1.a9 (A3), U2.11, U6.5, U9.7 (A3)
/A4: J1.a10 (A4), U9.6 (A4)
/A5: J1.a11 (A5), U9.5 (A5)
/A6: J1.a12 (A6), U9.4 (A6)
/A7: J1.a13 (A7), U9.3 (A7)
/A8: J1.a14 (A8), U9.25 (A8)
/A9: J1.a15 (A9), U9.24 (A9)
/A10: J1.a16 (A10), U9.21 (A10)
/A11: J1.a17 (A11), U9.23 (A11)
/A12: J1.a18 (A12), U9.2 (A12)
/A13: J1.a19 (A13), U6.13, U9.20 (~CE)
/A14: J1.a20 (A14), U4.2
/A15: J1.b22 (A15), U4.12
/A16: J1.a23 (A16), U4.9
/A17: J1.a24 (A17), U4.6
/A18: J1.a25 (A18), U6.10
/A19: J1.a26 (A19), U6.9
/CLK: U2.6, U8.18 (CLK)
/D0: J1.b29 (D0), U5.3 (D0), U8.5 (DI0), U9.11 (D0)
/D1: J1.b30 (D1), U5.4 (D1), U8.6 (DI1), U9.12 (D1)
/D2: J1.b31 (D2), U5.6 (D2), U8.7 (DI2), U9.13 (D2)
/D3: J1.a31 (D3), U5.11 (D3), U8.8 (DI3), U9.15 (D3)
/D4: J1.a30 (D4), U8.9 (DI4), U9.16 (D4)
/D5: J1.a29 (D5), U8.10 (DI5), U9.17 (D5)
/D6: J1.a28 (D6), U8.11 (DI6), U9.18 (D6)
/D7: J1.a27 (D7), U8.12 (DI7), U9.19 (D7)
/DATA_RD: J2.30, RP2.5 (R4), U8.19 (~RD)
/DATA_WR: J2.22, U7.9 (O0b)
/DIR: J2.18, U7.7 (O1b)
/DS: J1.b27 (~DS), U3.9, U3.10
/DS0: J2.10, U7.18 (O0a)
/DS1: J2.12, U7.16 (O1a)
/DSMC: J1.a6 (~DSMC), Q1.1 (E)
/DTACKL: J1.b25 (~DTACK), U3.11
/EXTINT: J1.b3 (~EXTINT)
/FDCON_CS: RP2.7 (R6), U3.6, U8.1 (~CS)
/FDCON_DEN: U5.10 (Q3), U8.26 (~DDEN)
/FDC_DIR: U7.13 (I1b), U8.17 (DIRC)
/FDC_MOTOR: U7.15 (I2b), U8.20 (MOTOR)
/FDC_STEP: U7.6 (I2a), U8.16 (STEP)
/FDC_WD: U7.11 (I0b), U8.22 (WD)
/FDC_WG: U7.8 (I3a), U8.21 (WG)
/FDSET_CS: U5.9 (Cp), U6.6
/GATE_WR: J2.24, U7.12 (O3a)
/HEAD: J2.32, U7.3 (O3b)
/INDEX: J2.8, RP2.2 (R1), U8.24 (~IP)
/MOTOR_ON: J2.16, U7.5 (O2b)
/RESET: J1.b21 (~RESETCPU), U5.1 (~Mr), U8.13 (~MR)
/ROM_OE: U2.9, U6.8, U9.22 (~OE)
/RW: J1.b26 (~DRW), U8.2 (R/~W)
/SP0: J1.a4 (SP0), U4.1
/SP1: J1.a5 (SP1), U4.13
/SP2: J1.a7 (SP2), U4.8
/SP3: J1.b7 (SP3), U4.5
/STEP: J2.20, U7.14 (O2a)
/TRACK_0: J2.26, RP2.3 (R2), U8.23 (~TR00)
/WRITE_PROT: J2.28, RP2.4 (R3), U8.25 (~WPRT)
/XOR_PULLUP: RP2.8 (R7), U4.3, U4.4, U4.10, U4.11, U6.11
GND: C1.2, C2.2, C3.2, C5.2, C6.2, C7.2, C8.2, C9.2, C10.2, J1.a32 (GND), J1.b32 (GND), J2.1, J2.3, J2.5, J2.7, J2.9, J2.11, J2.13, J2.15, J2.17, J2.19, J2.21, J2.23, J2.25, J2.27, J2.29, J2.31, J2.33, U1.2 (GND), U2.7 (GND), U3.7 (GND), U4.7 (GND), U5.8 (GND), U6.7 (GND), U7.1 (OEa), U7.10 (GND), U7.19 (OEb), U8.14 (GND), U9.14 (GND)
unnamed: Q1.2 (B), RN1.5 (R3.1), U2.8, U3.12, U6.1
unnamed: C4.2, RN1.1 (R1.1), U2.1
unnamed: RN1.2 (R1.2), U2.2, Y1.1
unnamed: RN1.3 (R2.1), U2.3, Y1.2
unnamed: C3.1, C4.1, RN1.4 (R2.2), U2.4, U2.5
unnamed: RN1.8 (R4.2), U3.8, U3.13, U6.2, U6.3
unnamed: RP2.6 (R5), U3.1, U3.2, U8.28 (INTRQ)
unnamed: U2.10, U3.5
unnamed: U2.12, U3.4, U6.4
unnamed: U2.13, U6.12
unnamed: U5.2 (Q0), U7.17 (I3b)
unnamed: U5.5 (Q1), U7.2 (I0a)
unnamed: U5.7 (Q2), U7.4 (I1a)

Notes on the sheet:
== STUGART INT. ==
NOTE: In V4 there is aditional inverter, because FDSET_CS is active on raise so it's late timing in V3. Aparently work anyway.
PIN 3 is KEY, N/A
<- MOTOR 0
HEAD
-> DS3
NOTE: Aparently in original PCB U4 pins 2,3 are joined. shall be 3,4 but work anyway.
<- DS0
<- DS1
-> READY / Disc Chan.
DENSITY
-> Disc Chan. Detected
<- MOTOR 1
NOTE: Aparently in original PCB C8 is connect to pin 3 of U6 and its fixed from factory.
Of the 16Kb are allocated for ROM the first 8Kb and the last are used for I/O
N/C
-> DS2
DISC 1
== AT INTERFACE ==
<- DENSITY SEL
DISC 0

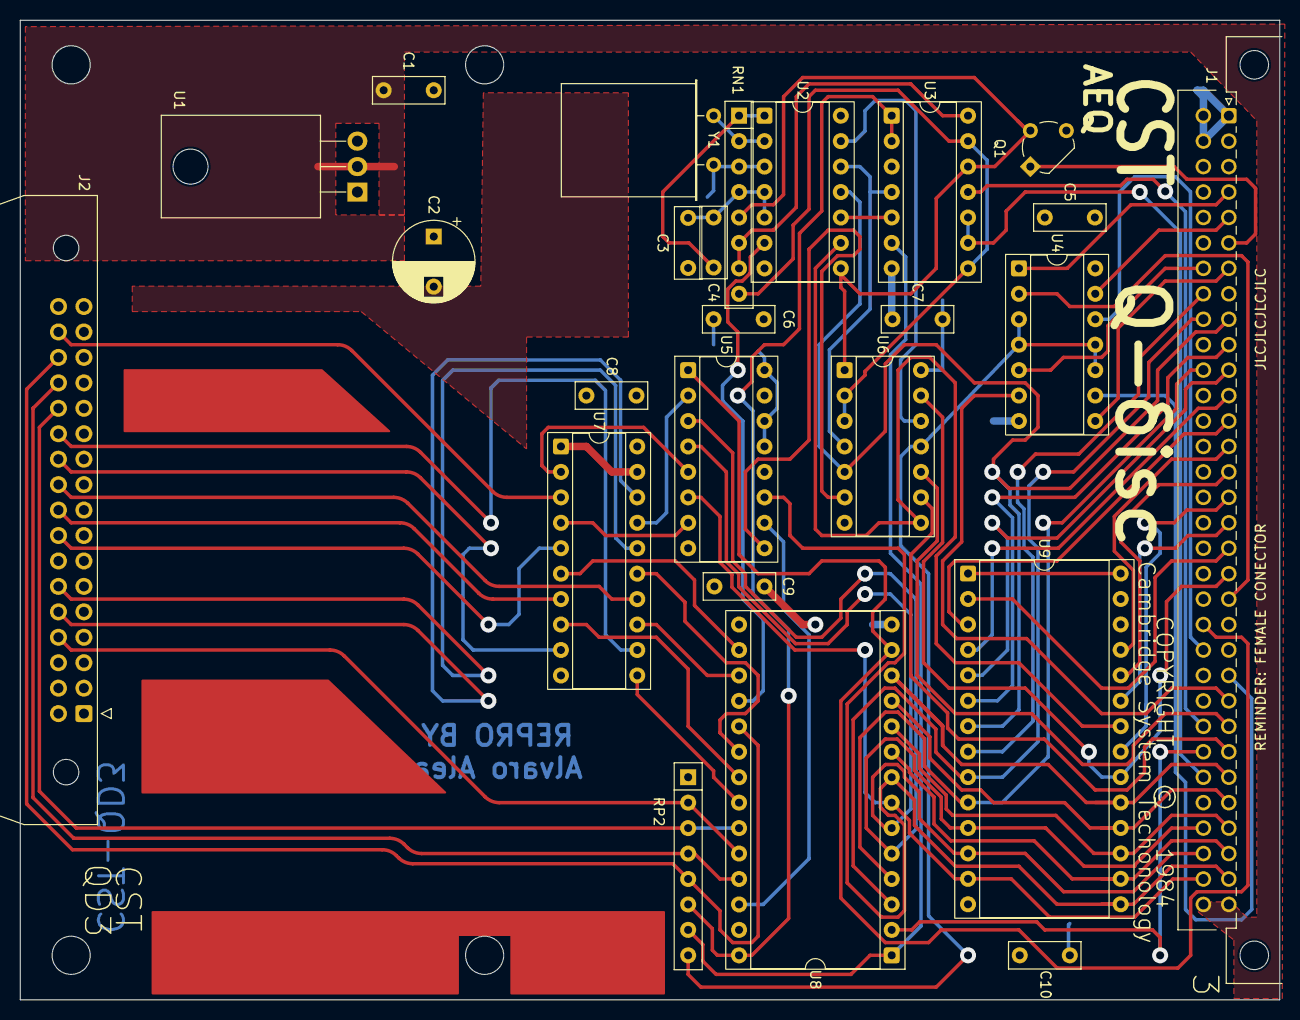
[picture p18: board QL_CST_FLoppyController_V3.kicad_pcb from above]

Board: 2 copper layers, 125.7 x 97.8 mm, 25 parts (0 on the bottom side), 76 nets.

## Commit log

2023-05-20 Finish Schematic capture. Upgraded to Kicad 7. Ordered testing PCB
    [qdisk_v4-B_Cu.gbr, qdisk_v4-B_Mask.gbr, qdisk_v4-B_Silkscreen.gbr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]
2023-05-20 Remove background images so PCB 50MB -> 500kB
2023-06-16 Add manual, 3d case and small corrections
    [carcasa_V2.FCStd, case.stl, lid.stl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]
2023-06-17 Small corrections in the 3D model of the case
    [carcasa_V2.FCStd, case.stl, lid.stl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]
2025-04-27 initial Issue 3
    [QL_CST_FLoppyController_V3.kicad_pcb, QL_CST_FLoppyController_V3.kicad_sch, qdisk_v4.kicad_pcb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]

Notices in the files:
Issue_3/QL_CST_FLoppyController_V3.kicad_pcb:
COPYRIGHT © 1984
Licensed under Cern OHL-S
